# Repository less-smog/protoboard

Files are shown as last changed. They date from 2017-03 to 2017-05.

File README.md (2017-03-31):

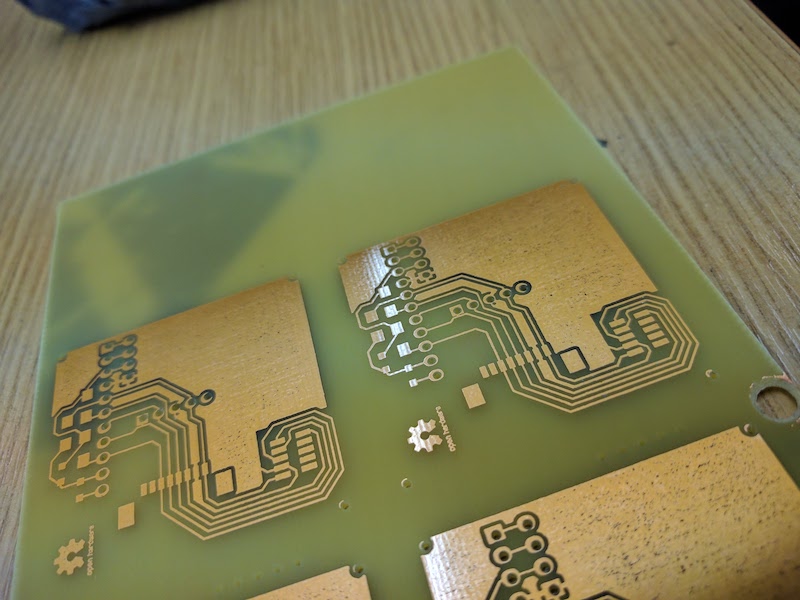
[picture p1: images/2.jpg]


TODO:

* Align I2C output pins with the rest, so that the pins can be plugged into the edge of a protoboard.
* Move resistors and diodes to reduce offset from the edge - ideally there should be none.
* SDS011 connector should be an angled connector, close to the edge of the board.

## Subtree workflow

### Inject

```
git subtree add --prefix vendor/lolin https://github.com/tommck/LoLin_Designs.git master --squash
```

### Update

```
git subtree pull --prefix vendor/lolin https://github.com/tommck/LoLin_Designs.git master --squash
```

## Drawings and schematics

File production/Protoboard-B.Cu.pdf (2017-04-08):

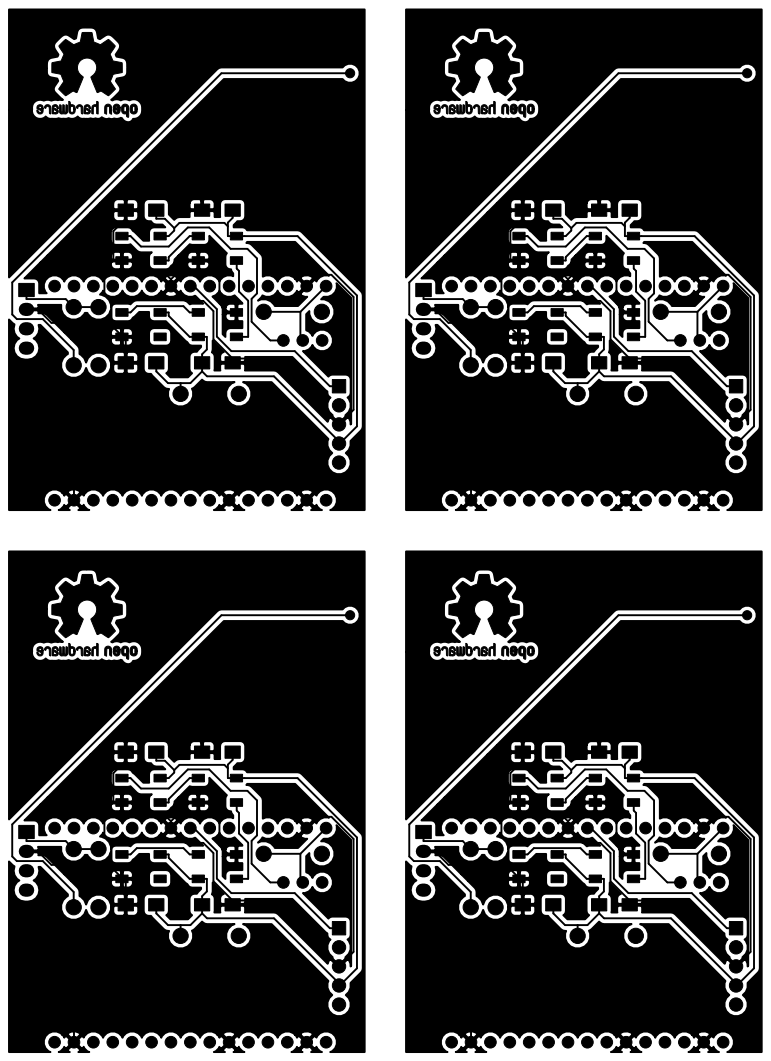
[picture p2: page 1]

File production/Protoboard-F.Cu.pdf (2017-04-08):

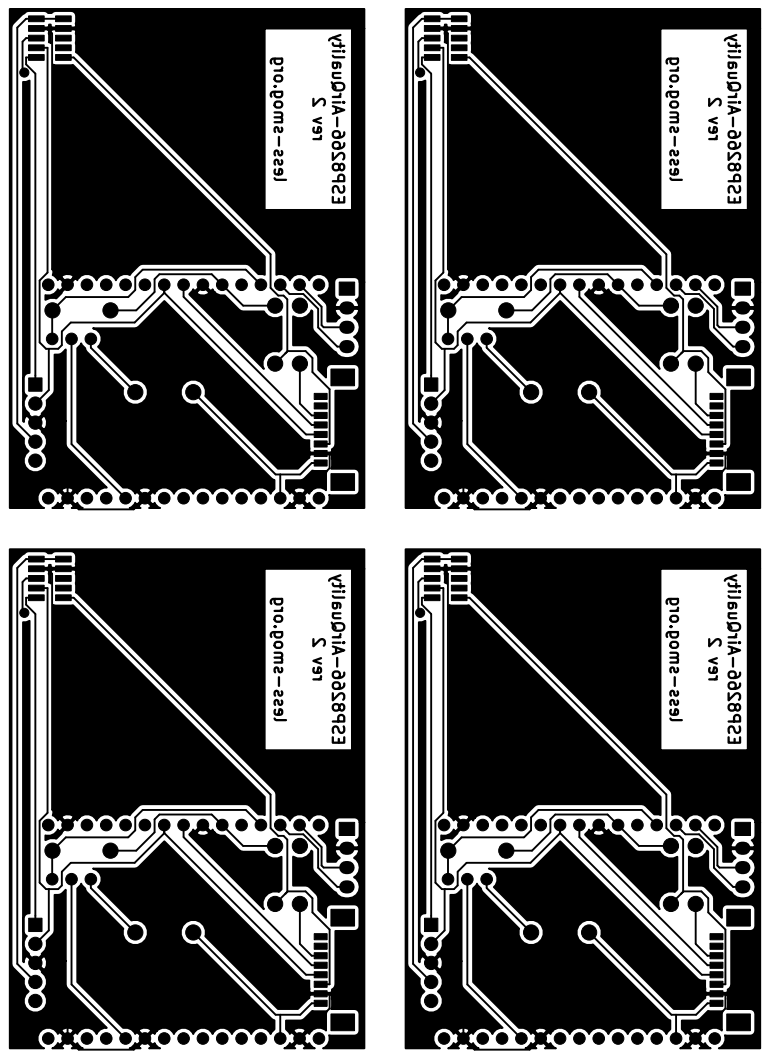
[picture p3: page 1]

ESP8266-AirQuality rev 2 less-smog.org ESP8266-AirQuality rev 2 less-smog.org

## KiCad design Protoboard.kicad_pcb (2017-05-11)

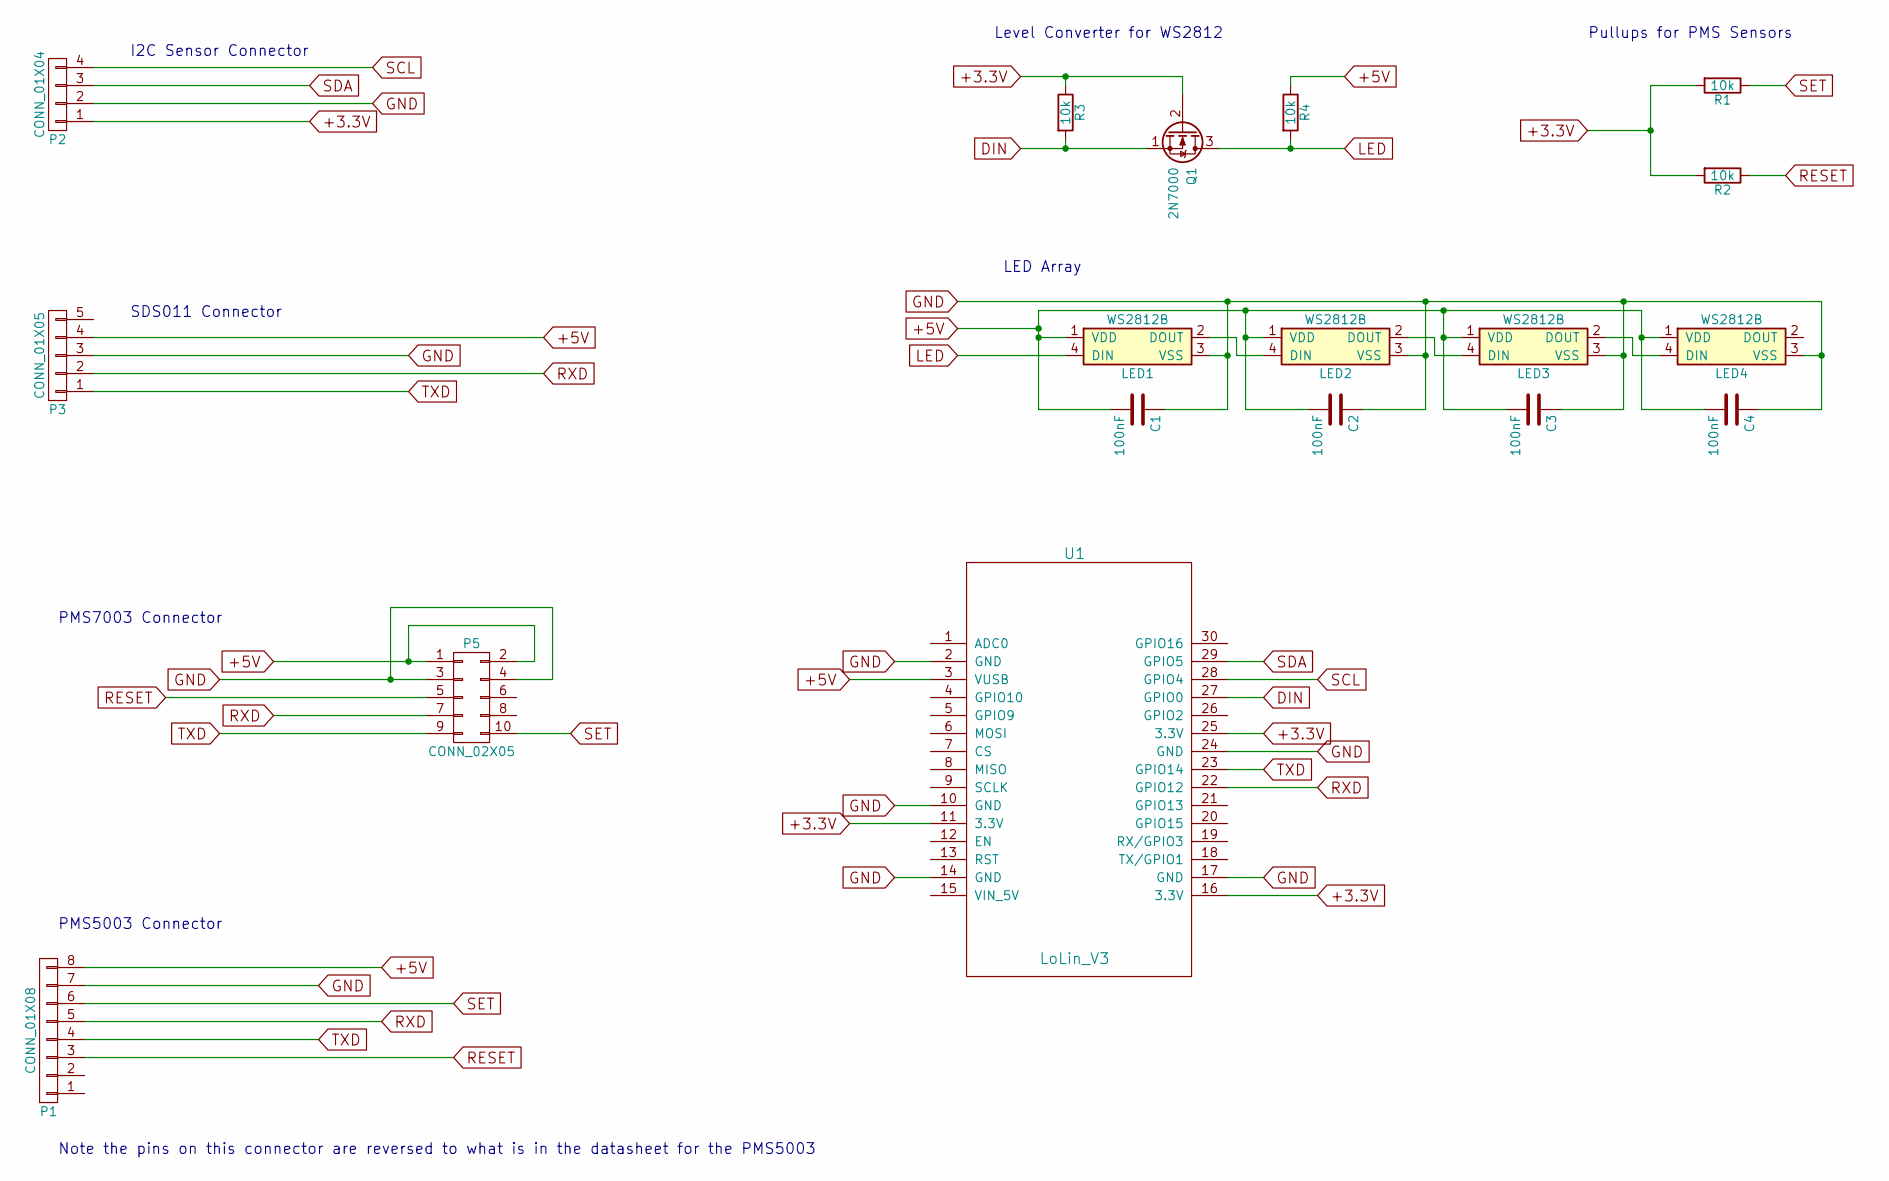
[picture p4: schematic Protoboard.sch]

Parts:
C1, C2, C3, C4: 100nF; C_1206_HandSoldering
LED1, LED2, LED3, LED4: WS2812B; LED_WS2812B-PLCC4
P1: CONN_01X08; Molex_PicoBlade_53261-0871_08x1.25mm_Angled
P2: CONN_01X04; Pin_Header_Straight_1x04
P3: CONN_01X05; JST_XH_S05B-XH-A_05x2.50mm_Angled
P5: CONN_02X05; Amphenol
Q1: 2N7000; TO-92_Inline_Wide
R1, R2, R3, R4: 10k; Resistor_Horizontal_RM7mm
U1: LoLin_V3; LoLin

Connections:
+3.3V: P2.1, Q1.2 (G), R1.2, R2.2, R3.1, U1.11 (3.3V), U1.16 (3.3V), U1.25 (3.3V)
+5V: C1.2, C2.2, C3.2, C4.2, LED1.1 (VDD), LED2.1 (VDD), LED3.1 (VDD), LED4.1 (VDD), P1.8, P3.4, P5.1, P5.2, R4.1, U1.3 (VUSB)
DIN: Q1.1 (S), R3.2, U1.27 (GPIO0)
GND: C1.1, C2.1, C3.1, C4.1, LED1.3 (VSS), LED2.3 (VSS), LED3.3 (VSS), LED4.3 (VSS), P1.7, P2.2, P3.3, P5.3, P5.4, U1.2 (GND), U1.10 (GND), U1.14 (GND), U1.17 (GND), U1.24 (GND)
LED: LED1.4 (DIN), Q1.3 (D), R4.2
unnamed: LED1.2 (DOUT), LED2.4 (DIN)
unnamed: LED2.2 (DOUT), LED3.4 (DIN)
unnamed: LED3.2 (DOUT), LED4.4 (DIN)
RESET: P1.3, P5.5, R2.1
RXD: P1.5, P3.2, P5.7, U1.22 (GPIO12)
SCL: P2.4, U1.28 (GPIO4)
SDA: P2.3, U1.29 (GPIO5)
SET: P1.6, P5.10, R1.1
TXD: P1.4, P3.1, P5.9, U1.23 (GPIO14)

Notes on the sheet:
I2C Sensor Connector
SDS011 Connector
PMS7003 Connector
PMS5003 Connector
Pullups for PMS Sensors
Level Converter for WS2812
Note the pins on this connector are reversed to what is in the datasheet for the PMS5003
LED Array

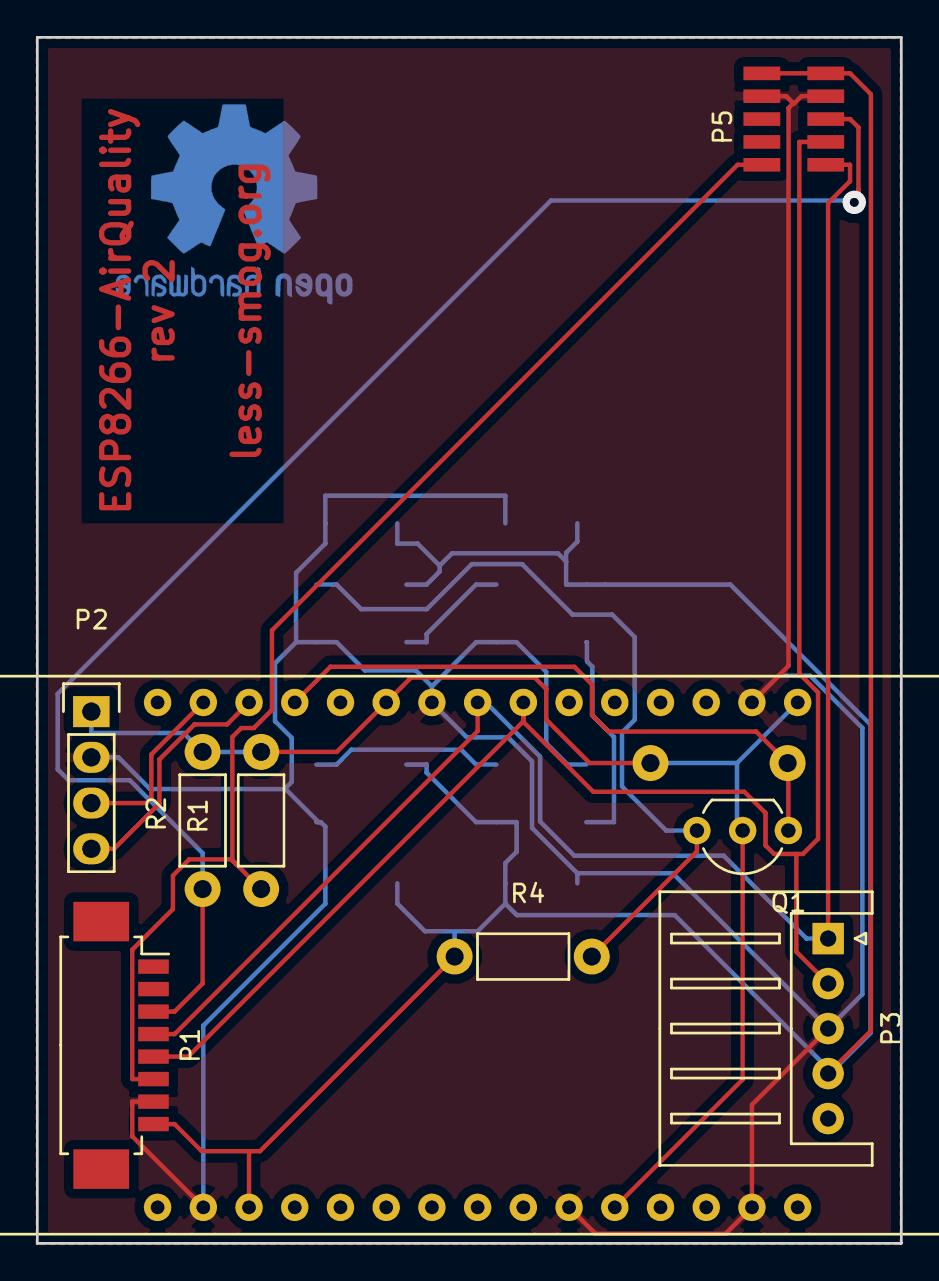
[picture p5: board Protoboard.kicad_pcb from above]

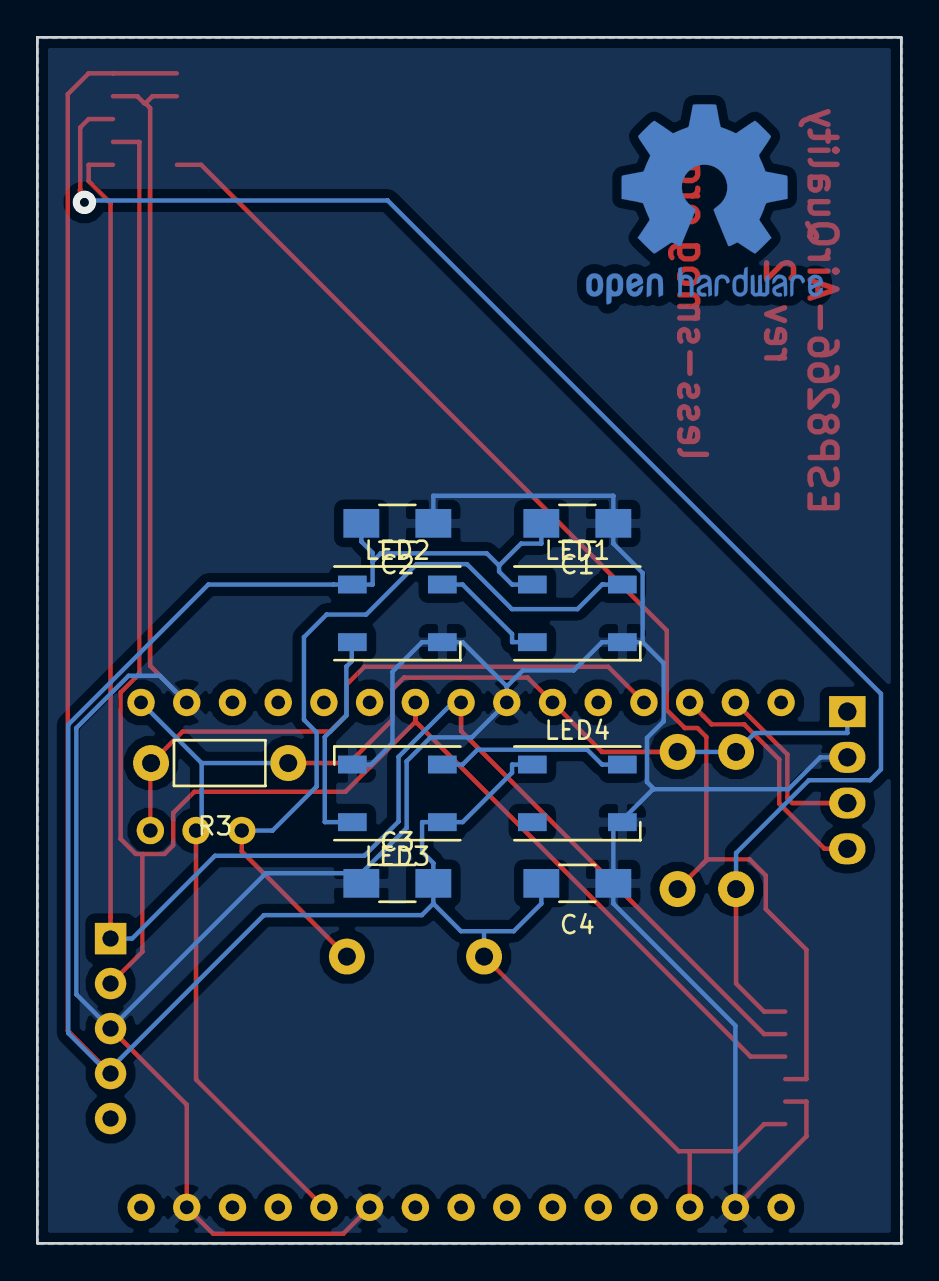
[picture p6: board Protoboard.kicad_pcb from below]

Board: 2 copper layers, 48.0 x 67.0 mm, 18 parts (9 on the bottom side), 14 nets.

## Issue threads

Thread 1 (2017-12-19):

Investigate if it would be possible to power the board using 18650 batteries and a small solar panel

jasiek, 2017-12-19:
* What does the board consume in terms of power and at what stages?
* Determine if it would be possible to charge batteries and what sort of charge/discharge time would work?
* What sort of a charging circuit and solar cell should be used?
* How will it affect the footprint of the board?
* Is this sufficient to make the board completely autonomous?

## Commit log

2017-03-11 Initial commit.
    [Protoboard.kicad_pcb, Protoboard.sch]
2017-03-11 Updated footprints for most things.
    [Protoboard.sch]
2017-03-12 Added a drawing for RS part no http://uk.rs-online.com/web/p/pcb-sockets/7944590/?sra=pstk
    [Protoboard.sch]
2017-03-12 Routing done.
    [Protoboard.kicad_pcb, Protoboard.sch]
2017-03-13 Generated drill files and stencils.
    [Protoboard.kicad_pcb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]
2017-03-14 Moved tracks around.
    [Protoboard.kicad_pcb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]
2017-03-14 Added holes to denote corners of the board. Regenerated outputs.
    [Protoboard.kicad_pcb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]
2017-03-15 Added sample image.
2017-03-18 Reorganized board, fixed bug with Molex Microblade connector (reversed pins).
    [Protoboard.kicad_pcb, Protoboard.sch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]
2017-03-19 Improved track spacing for home brew UV etching.
    [Protoboard.kicad_pcb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]
2017-03-20 Non-reversed drill file.
    [Protoboard.drl]
2017-03-31 Added WS2812B leds.
    [Protoboard.sch]
2017-03-31 Minor changes.
    [Protoboard.sch]
2017-03-31 Squashed 'vendor/lolin/' content from commit abab765
    git-subtree-dir: vendor/lolin
    git-subtree-split: abab76525bdcf2ff2177c4e4450d0f7e94bf356f
    [LoLin.kicad_pcb, LoLin.sch]
2017-03-31 Routing and fill zones.
    [Protoboard.kicad_pcb, Protoboard.sch]
2017-03-31 Fab outputs.
    [Protoboard.drl]
2017-03-31 Moved PMS7003 connector 4mm towards the edge and regenerated all fab artifacts.
    [Protoboard.kicad_pcb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]
2017-03-31 Tigten boards together to fix on a 10x16 cm board.
    [Protoboard.kicad_pcb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]
2017-04-01 Removed drilling holes from corners and regenerated drill file.
    [Protoboard.kicad_pcb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]
2017-04-08 Removed gerber files.
    This is rev 2
    [Protoboard.kicad_pcb, Protoboard.sch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]
2017-04-08 Print options?
    [Protoboard.kicad_pcb]
2017-05-11 Adjusted via sized for production.
    Inner fi = 0.4mm min
    Outer fi = 1.2mm min
    [Protoboard-B.Adhes.gbr, Protoboard-B.CrtYd.gbr, Protoboard-B.Cu.gbr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]
